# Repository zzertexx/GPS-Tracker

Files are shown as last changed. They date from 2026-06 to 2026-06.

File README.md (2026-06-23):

# GPS Tracker
### Use this bracelet to get live location and watch on any device 
> do not use to stalk people by giving them "unsuspicious" bracelet and looking where they are!!

## Zine


## Images

a


tracker-1
pcb-1

## How to use?
1. Order components from Bill of Materials and 3D Print case
2. Solder electronics and assembly into case
3. Insert SIM-Card with cellular data over 2G 
4. place your parameters in firmware "modem.h" line 5 and 8
5. Open Firmware via nRF connect in VS Code using Add existing application
6. Add build configuration: board: nRF52dk_nRF52832
7. Wait for build -> connect to board via SWD: github.com/AndruPol/nrf52832-recover

## Features
* Button to Sleep/Wake
* LED indicator of work status
* BLE advertising for future app
* Send location data to personal Google Sheet
* Charge with Type-C
* Compatible with lots of watch straps

> In current version, software may have significant bugs, improper code, not enough features, but I will edit/fix as I get hardware to debug

## 4-layer PCB
**Built in KiCad 10.99 night build**
> You can't export 3D model in default KiCad 10.0.3 because of error   
Ignore User.Comments

1 Layer - F.Cu  
2 Layer - 3.3V  
3 Layer - GND  
4 Layer - B.Cu  

## Why did I build it?
My bro asked me if I can build one. I don't have any interest for GPS locators, or needness for one. I just wanted to try myself in designing Wearable and also help my bro, so I did it and I felt real hardship of building in limited space. Currently my design is really bad and MUST be fixed in next updates by tightening free space. 

## Bill of Materials
| Name | Quantity |
| --- | --- |
| nRF52832 | x1 |
| CH340C | x1 |
| USB-C 14 pin | x1 |
| TP4056-42-ESOP8 | x1 |
| FS8205A | x1 |
| DW01A | x1 |
| XC6206P332MR-G | x1 |
| TXS0102DCUR | x1 |
| XUNPU SMN-303 | x1
| A7680C-LANV | x1 |
| ZIISOR TX4G-FPC-4015 | x1 |
| 16-213SURC/S530-A4/TR8 | x1 |
| 2450AT18A100E | x1 |
| NX2016SA-32MHZ | x1 |
| SC-20S,32.768kHz | x1 |
| BLM21PG300SN1D | x1 |
| ESDBW5V0A1 | x1 |
| LXES15AAA1-153 | x1 |
| L80-R | x1 |
| 500 mAh 503040 Battery | x1 |
| Straps - Galaxy watch 6 18mm | x1 |
| ST-LINK V2 | x1 |
| B3U-3000P LED Diode | x1 |
| LXES15AAA1-153 | x1 |
| 100nF C | x14 |
| 10uF C | x2 |
| 1uF C | x4 |
| 12pF C | x6 |
| 100uF C | x2 |
| 4.7uF C | x1 |
| 0.8pF C | x1 |
| 10pF C | x1 |
| 33pF C | x1 |
| 100pF C | x1 |
| 10pF C | x1 |
| 1.2K R | x1 |
| 1K R | x3 |
| 100 R | x5 |
| 5.1K R | x2 |
| 10K R | x1 |
| 0 R | x1 |
| 10uH L | x1 |
| 3.9nH L | x1 |
| 15nH L | x1 |
| M2 Screws | x8 |

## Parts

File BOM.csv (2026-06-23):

Component | ID | Price
nRF52832 | C77540 | $3,63 | https://www.lcsc.com/product-detail/C77540.html
CH340C | C84681 | $0,63 | https://www.lcsc.com/product-detail/C84681.html
USB-C 14 pin | C165948 | $0,18 | https://www.lcsc.com/product-detail/C165948.html
TP4056-42-ESOP8 | C16581 | $0,19 | https://www.lcsc.com/product-detail/C16581.html
FS8205A | C908265 | $0,07 | https://www.lcsc.com/product-detail/C908265.html
DW01A | C351410 | $0,04 | https://www.lcsc.com/product-detail/C351410.html
XC6206P332MR-G | C5446 | $0,11 | https://www.lcsc.com/product-detail/C5446.html
TXS0102DCUR | C53434 | $0,20 | https://www.lcsc.com/product-detail/C53434.html
XUNPU SMN-303 - SIM Card | C266888 | $0,48 | https://www.lcsc.com/product-detail/C266888.html
A7680C-LANV | C5381968 | $3,89 | https://www.lcsc.com/product-detail/C5381968.html
ZIISOR TX4G-FPC-4015 - Antenna for 2G | C454896 | $0,38 | https://www.lcsc.com/product-detail/C454896.html
16-213SURC/S530-A4/TR8 - Red LED | C74339 | $0,03 | https://www.lcsc.com/product-detail/C74339.html
2450AT18A100E - nRF antenna | C89334 | $0,52 | https://www.lcsc.com/product-detail/C89334.html
NX2016SA-32MHZ - 32MHz crystal | C5441424 | $0,44 | https://www.lcsc.com/product-detail/C5441424.html
SC-20S,32.768kHz - crystal | C97603 | $0,24 | https://www.lcsc.com/product-detail/C97603.html
BLM21PG300SN1D - Ferrite Bead | C16903 | $0,03 | https://www.lcsc.com/product-detail/C16903.html
ESDBW5V0A1 - A7680C TVS | C5173252 | $0,06 | https://www.lcsc.com/product-detail/C5173252.html
LXES15AAA1-153 - Antenna TVS | C5210978 | $0,04 | https://www.lcsc.com/product-detail/C5210978.html
L80-R | Aliexpress | $5,00 | https://aliexpress.ru/item/1005009368056644.html?sku_id=12000048887115112
Battery | Aliexpress | $3,66 | https://aliexpress.ru/item/1005008217717191.html?shpMethod=Other&sku_id=12000044268208548
Straps - Galaxy watch 6 18mm | Aliexpress | $1,18 | https://aliexpress.ru/item/1005007219292840.html?sku_id=12000039849739042
ST-LINK V2 | Aliexpress | $1,30 | https://aliexpress.ru/item/1005006144093275.html?sku_id=12000035958608625
B3U-3000P LED Diode | C963349 | $1,43 | https://www.lcsc.com/product-detail/C963349.html
Capacitors
CL05B104KO5NNNC - C 100nF | C1525 | $0,01 | https://www.lcsc.com/product-detail/C1525.html
CL10A106KP8NNNC - C 10uF | C19702 | $0,02 | https://www.lcsc.com/product-detail/C19702.html
CL10A105KB8NNNC - C 1uF | C15849 | $0,01 | https://www.lcsc.com/product-detail/C15849.html
0402CG120J500NT - C 12pF | C1547 | $0,01 | https://www.lcsc.com/product-detail/C1547.html
CK1A101M-CRD54 - C 100uF | C3001231 | $0,03 | https://www.lcsc.com/product-detail/C3001231.html
CL10A475KO8NNNC - C 4.7uF | C19666 | $0,01 | https://www.lcsc.com/product-detail/C19666.html
CL10C0R8BB8NNNC - C 0.8pF | C21357 | $0,01 | https://www.lcsc.com/product-detail/C21357.html
CL05C100JB5NNNC - C 10pF | C32949 | $0,01 | https://www.lcsc.com/product-detail/C32949.html
0402CG330J500NT - C 33pF | C1562 | $0,01 | https://www.lcsc.com/product-detail/C1562.html
0402CG101J500NT - C 100pF | C1546 | $0,01 | https://www.lcsc.com/product-detail/C1546.html
Resistors
0603WAF1201T5E - R 1.2K | C22765 | $0,01 | https://www.lcsc.com/product-detail/C22765.html
0402WGF1001TCE - R 1K | C11702 | $0,01 | https://www.lcsc.com/product-detail/C11702.html
0402WGF1000TCE - R 100 | C25076 | $0,01 | https://www.lcsc.com/product-detail/C25076.html
0402WGF5101TCE - R 5.1K | C25905 | $0,01 | https://www.lcsc.com/product-detail/C25905.html
0805W8F1002T5E - R 10K | C17414 | $0,01 | https://www.lcsc.com/product-detail/C17414.html
0402WGF0000TCE R - 0 | C17168 | $0,01 | https://www.lcsc.com/product-detail/C17168.html
Inductors
SDFL2012S100KTF - L 10uH | C1046 | $0,05 | https://www.lcsc.com/product-detail/C1046.html
SDCL1005C3N9STDF - L 3.9nH | C14033 | $0,01 | https://www.lcsc.com/product-detail/C14033.html
SDCL1005C15NJTDF - L 15nH | C27143 | $0,01 | https://www.lcsc.com/product-detail/C27143.html

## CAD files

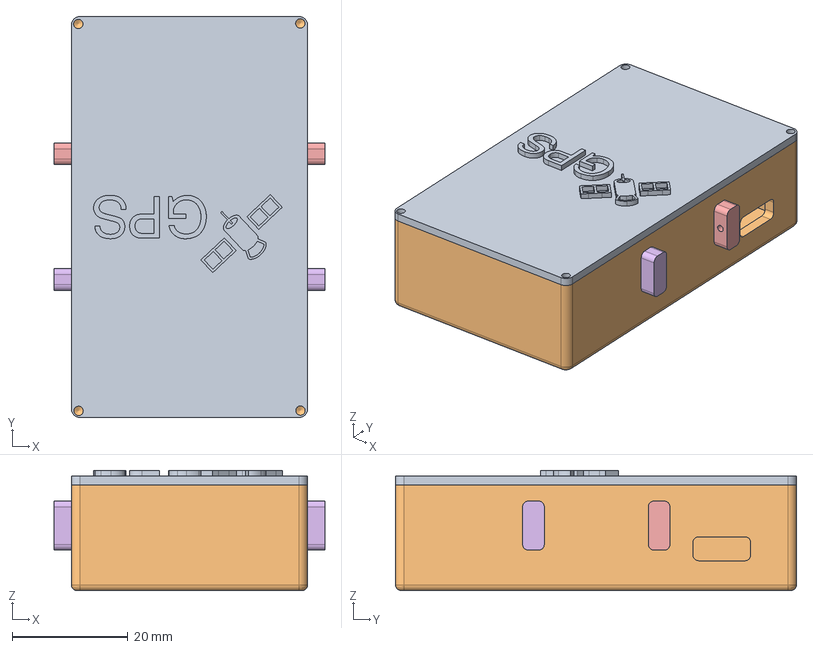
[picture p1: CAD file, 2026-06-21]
CAD/GPS_Case.step
46.9 x 69.4 x 20.8 mm

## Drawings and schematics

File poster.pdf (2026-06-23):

# GPS Tracker

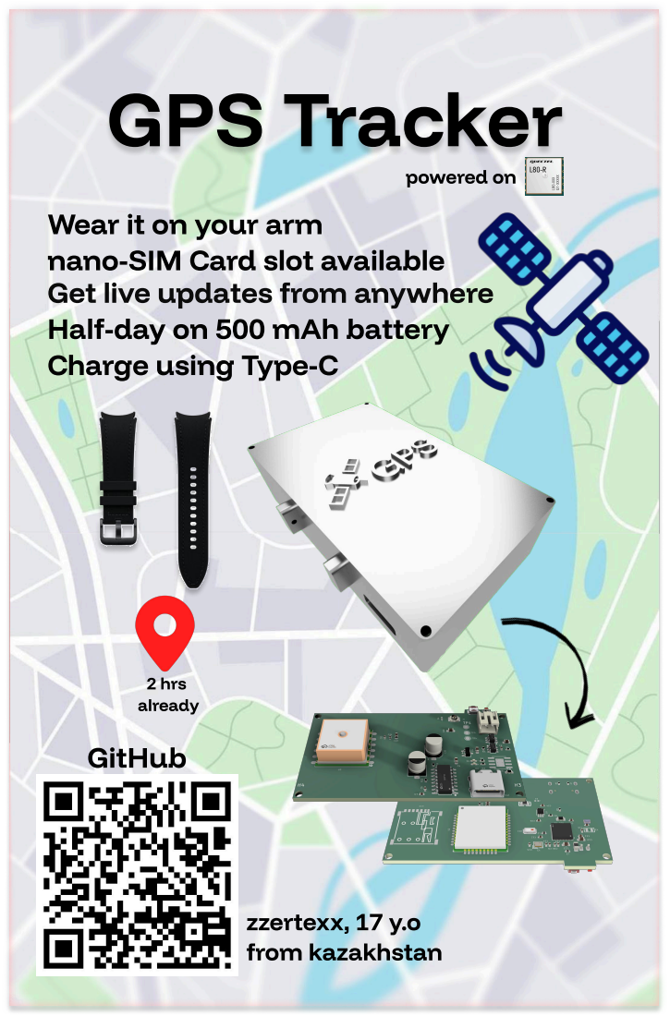
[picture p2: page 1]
powered on; 2 hrs; already; GitHub; zzertexx, 17 y.o; from kazakhstan

Wear it on your arm
nano-SIM Card slot available
Get live updates from anywhere
Half-day on 500 mAh battery
Charge using Type-C

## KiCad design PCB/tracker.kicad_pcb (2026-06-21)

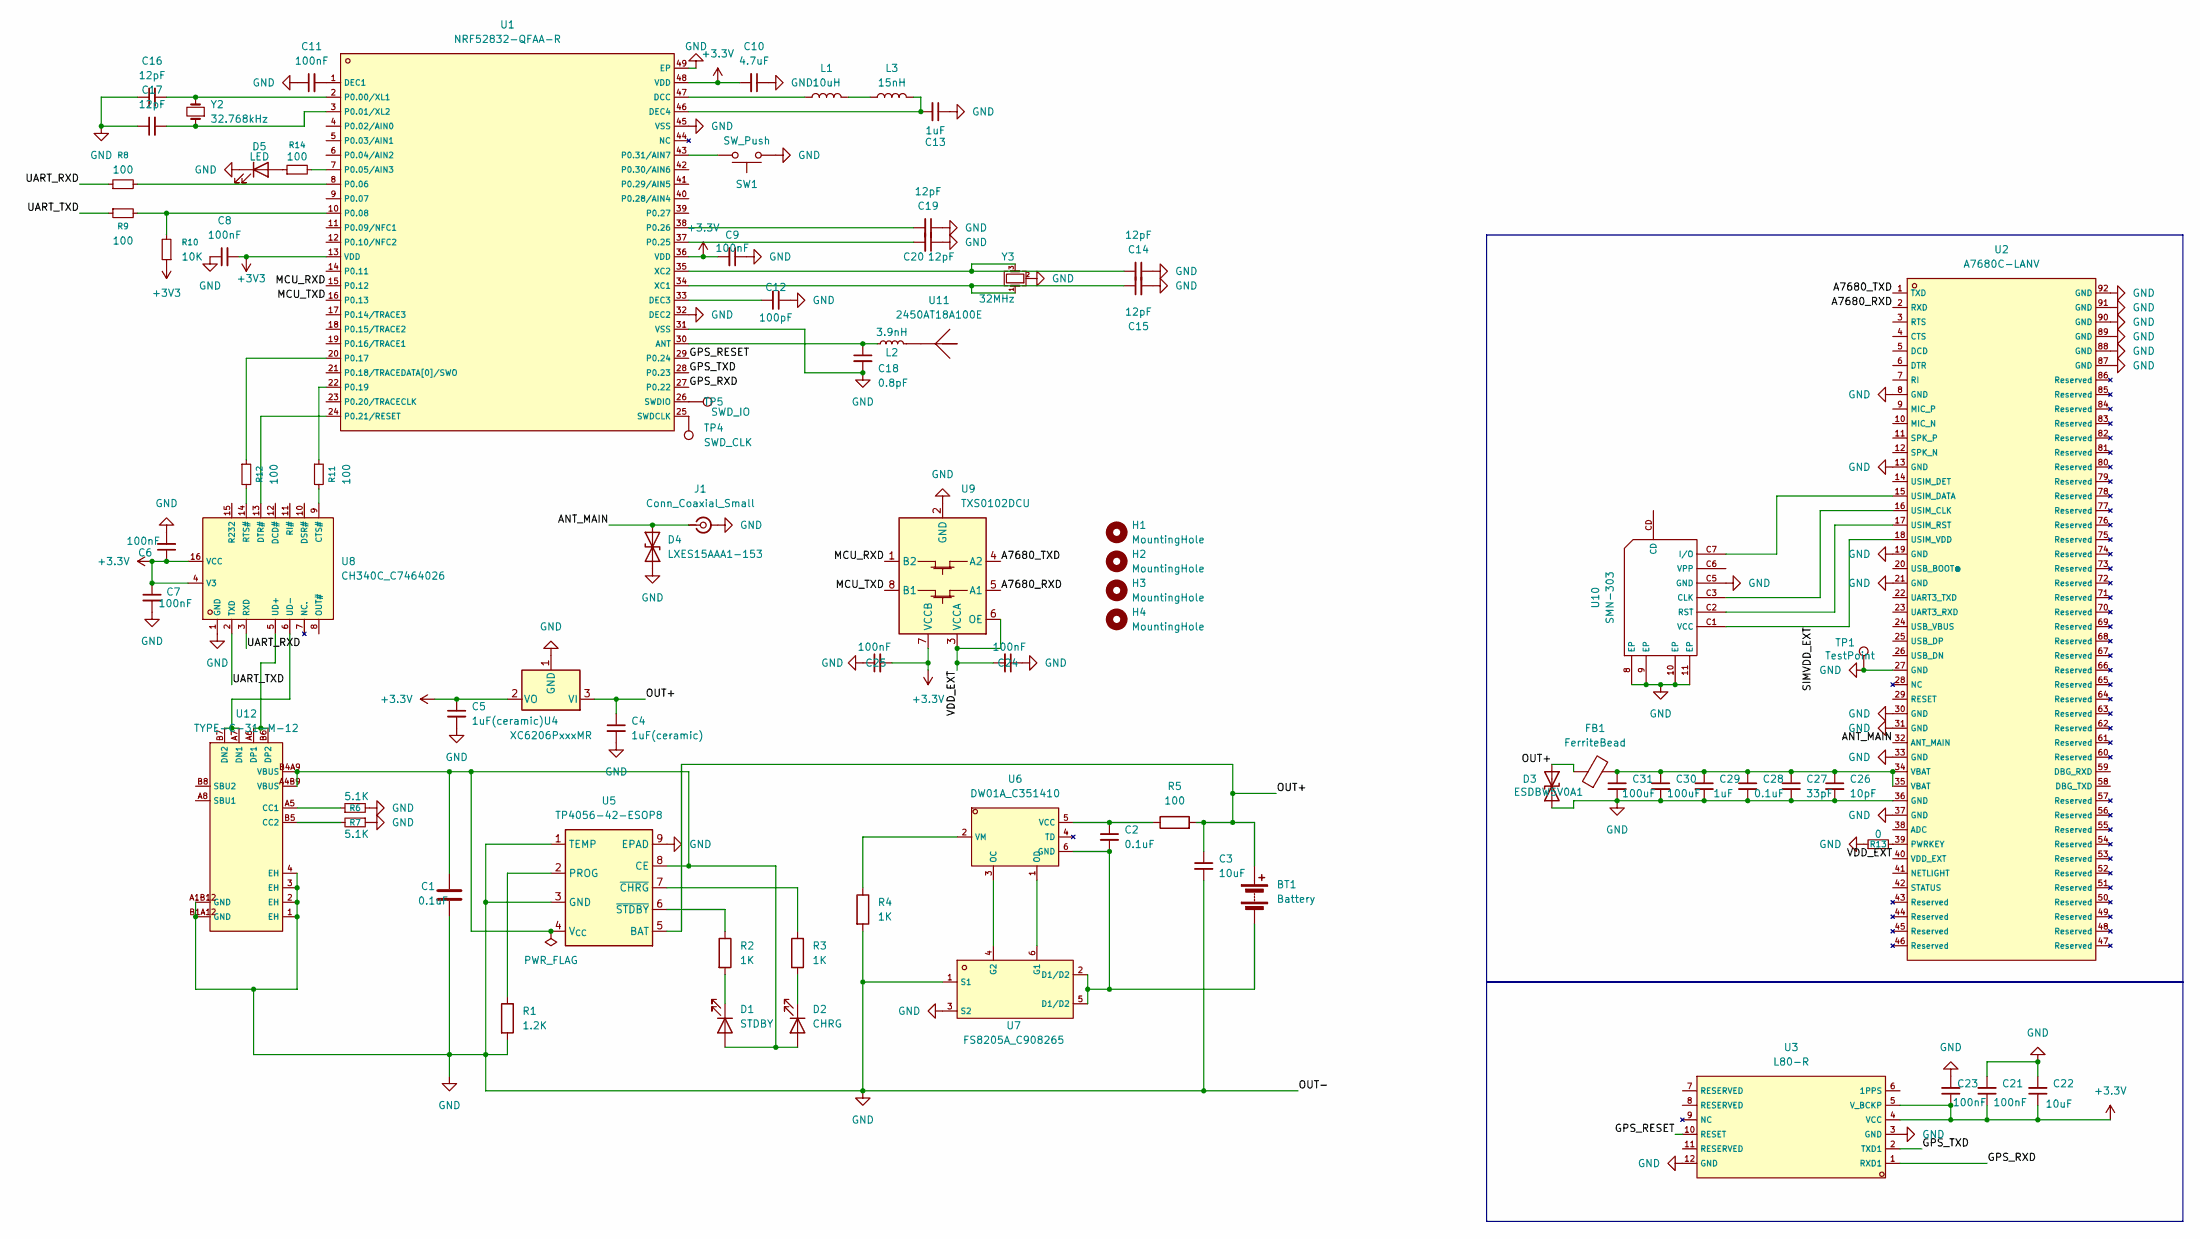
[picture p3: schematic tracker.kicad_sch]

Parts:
BT1: Battery; JST_PH_S2B-PH-K_1x02_P2.00mm_Horizontal
C1, C2, C28: 0.1uF; C_0402_1005Metric
C3, C22: 10uF; C_0603_1608Metric
C4, C5: 1uF(ceramic); C_0603_1608Metric
C6, C7, C8, C9, C11, C21, C23, C24, C25: 100nF; C_0402_1005Metric
C10: 4.7uF; C_0603_1608Metric
C12: 100pF; C_0402_1005Metric
C13, C29: 1uF; C_0603_1608Metric
C14, C15, C16, C17, C19, C20: 12pF; C_0402_1005Metric
C18: 0.8pF; C_0603_1608Metric_Pad1.08x0.95mm_HandSolder
C26: 10pF; C_0402_1005Metric
C27: 33pF; C_0402_1005Metric
C30, C31: 100uF; CP_Elec_5x5.4
D1: STDBY; LED_0402_1005Metric_Pad0.77x0.64mm_HandSolder
D2: CHRG; LED_0402_1005Metric_Pad0.77x0.64mm_HandSolder
D3: ESDBW5V0A1; D_0402_1005Metric
D4: LXES15AAA1-153; D_0402_1005Metric
D5: LED; LED_Kingbright_APA1606_1.6x0.6mm_Horizontal
FB1: FerriteBead; L0805
H1, H2, H3, H4: MountingHole; MountingHole_2.2mm_M2
J1: Conn_Coaxial_Small; U.FL_Hirose_U.FL-R-SMT-1_Vertical
L1: 10uH; L_0805_2012Metric
L2: 3.9nH; L_0402_1005Metric
L3: 15nH; L_0402_1005Metric
R1: 1.2K; R_0603_1608Metric
R2, R3, R4: 1K; R_0402_1005Metric
R5, R8, R9, R11, R12: 100; R_0402_1005Metric
R6, R7: 5.1K; R_0402_1005Metric
R10: 10K; R_0805_2012Metric
R13: 0; R_0402_1005Metric
R14: 100; C_0402_1005Metric
SW1: SW_Push; KEY-SMD_B3U-3000P
TP1: TestPoint; TestPoint_Pad_D1.5mm
TP4: SWD_CLK; TestPoint_Pad_D1.5mm
TP5: SWD_IO; TestPoint_Pad_D1.5mm
U1: NRF52832-QFAA-R; QFN-48_L6.0-W6.0-P0.40-BL-EP3.8; LCSC C77540
U2: A7680C-LANV; LCC-LAG_L17.6-W15.7_A7680C; LCSC C5381968
U3: L80-R; GPSM-SMD_L80-R; LCSC C188357
U4: XC6206PxxxMR; SOT-23-3
U5: TP4056-42-ESOP8; SOIC-8-1EP_3.9x4.9mm_P1.27mm_EP2.41x3.3mm_ThermalVias
U6: DW01A_C351410; SOT-23-6_L2.9-W1.6-P0.95-LS2.8-BL; LCSC C351410
U7: FS8205A_C908265; SOT-23-6_L2.9-W1.6-P0.95-LS2.8-BR; LCSC C908265
U8: CH340C_C7464026; SOP-16_L10.0-W3.9-P1.27-LS6.0-BL; LCSC C7464026
U9: TXS0102DCU; VSSOP-8_2.3x2mm_P0.5mm
U10: SMN-303; SIM-SMD_SMN-303; LCSC C266888
U11: 2450AT18A100E; ANT-SMD_L3.2-W1.6; LCSC C89334
U12: TYPE-C-31-M-12; USB-C_SMD-TYPE-C-31-M-12_1; LCSC C165948
Y2: 32.768kHz; OSC-SMD_L2.0-W1.2
Y3: 32MHz; CRYSTAL-SMD_4P-L2.0-W1.6-BL

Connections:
+3.3V: C5.1, C6.1, C7.1, C9.2, C10.2, C21.1, C22.1, C23.1, C25.2, U1.36 (VDD), U1.48 (VDD), U3.4 (VCC), U3.5 (V_BCKP), U4.2 (VO), U8.4 (V3), U8.16 (VCC), U9.7 (VCCB)
+3V3: C8.2, R10.1, U1.13 (VDD)
/A7680_RXD: U2.2 (RXD), U9.5 (A1)
/A7680_TXD: U2.1 (TXD), U9.4 (A2)
/ANT_MAIN: D4.2 (A2), J1.1 (In), U2.32 (ANT_MAIN)
/GPS_RESET: U1.29 (P0.24), U3.10 (RESET)
/GPS_RXD: U1.27 (P0.22), U3.1 (RXD1)
/GPS_TXD: U1.28 (P0.23), U3.2 (TXD1)
/MCU_RXD: U1.15 (P0.12), U9.1 (B2)
/MCU_TXD: U1.16 (P0.13), U9.8 (B1)
/OUT+: BT1.1 (+), C3.1, C4.1, D3.2 (A2), FB1.1, R5.2, U4.3 (VI), U5.5 (BAT)
/SIMVDD_EXT: U2.18 (USIM_VDD), U10.C1 (VCC)
/UART_RXD: R8.1, U8.3 (RXD)
/UART_TXD: R9.1, U8.2 (TXD)
/VDD_EXT: C24.2, U2.40 (VDD_EXT), U9.3 (VCCA), U9.6 (OE)
GND: C1.2, C3.2, C4.2, C5.2, C6.2, C7.2, C8.1, C9.1, C10.1, C11.1, C12.1, C13.1, C14.1, C15.2, C16.1, C17.1, C18.2, C19.1, C20.1, C21.2, C22.2, C23.2, C24.1, C25.1, C26.2, C27.2, C28.2, C29.2, C30.2, C31.2, D3.1 (A1), D4.1 (A1), D5.1 (K), J1.2 (Ext), R1.2, R4.2, R6.2, R7.1, R13.1, SW1.1, TP1.1 (1_1), U1.31 (VSS), U1.32 (DEC2), U1.45 (VSS), U1.49 (EP), U2.8 (GND), U2.13 (GND), U2.19 (GND), U2.21 (GND), U2.27 (GND), U2.30 (GND), U2.31 (GND), U2.33 (GND), U2.36 (GND), U2.37 (GND), U2.87 (GND), U2.88 (GND), U2.89 (GND), U2.90 (GND), U2.91 (GND), U2.92 (GND), U3.3 (GND), U3.12 (GND), U4.1 (GND), U5.1 (TEMP), U5.3 (GND), U5.9 (EPAD), U7.1 (S1), U7.3 (S2), U8.1 (GND), U9.2 (GND), U10.8 (EP), U10.9 (EP), U10.10 (EP), U10.11 (EP), U10.C5 (GND), U12.1 (EH), U12.2 (EH), U12.3 (EH), U12.4 (EH), U12.A1B12 (GND), U12.B1A12 (GND), Y3.2 (G), Y3.4 (G)
unnamed: BT1.2 (-), C2.2, U6.6 (GND), U7.2 (D1/D2), U7.5 (D1/D2)
unnamed: C26.1, C27.1, C28.1, C29.1, C30.1, C31.1, FB1.2, U2.34 (VBAT), U2.35 (VBAT)
unnamed: C1.1, D1.2 (A), D2.2 (A), U5.4 (V_{CC}), U5.8 (CE), U12.A4B9 (VBUS), U12.B4A9 (VBUS)
unnamed: D1.1 (K), R2.2
unnamed: D2.1 (K), R3.2
unnamed: D5.2 (A), R14.1
unnamed: L1.2, L3.1
unnamed: C18.1, L2.1, U1.30 (ANT)
unnamed: L1.1, U1.47 (DCC)
unnamed: C11.2, U1.1 (DEC1)
unnamed: C12.2, U1.33 (DEC3)
unnamed: C13.2, L3.2, U1.46 (DEC4)
unnamed: C16.2, U1.2 (P0.00/XL1), Y2.2
unnamed: C17.2, U1.3 (P0.01/XL2), Y2.1
unnamed: R14.2, U1.7 (P0.05/AIN3)
unnamed: R8.2, U1.8 (P0.06)
unnamed: R9.2, R10.2, U1.10 (P0.08)
unnamed: R12.1, U1.20 (P0.17)
unnamed: R11.1, U1.22 (P0.19)
unnamed: U1.24 (P0.21/RESET), U8.13 (DTR#)
unnamed: C20.2, U1.37 (P0.25)
unnamed: C19.2, U1.38 (P0.26)
unnamed: SW1.2, U1.43 (P0.31/AIN7)
unnamed: TP4.1 (1_1), U1.25 (SWDCLK)
unnamed: TP5.1 (1_1), U1.26 (SWDIO)
unnamed: C15.1, U1.34 (XC1), Y3.1
unnamed: C14.2, U1.35 (XC2), Y3.3
unnamed: R13.2, U2.39 (PWRKEY)
unnamed: R1.1, U5.2 (PROG)
unnamed: R3.1, U5.7 (~CHRG)
unnamed: R2.1, U5.6 (~STDBY)
unnamed: U6.3 (OC), U7.4 (G2)
unnamed: U6.1 (OD), U7.6 (G1)
unnamed: C2.1, R5.1, U6.5 (VCC)
unnamed: R4.1, U6.2 (VM)
unnamed: R11.2, U8.9 (CTS#)
unnamed: R12.2, U8.14 (RTS#)
unnamed: U2.16 (USIM_CLK), U10.C3 (CLK)
unnamed: U2.15 (USIM_DATA), U10.C7 (I/O)
unnamed: U2.17 (USIM_RST), U10.C2 (RST)
unnamed: L2.2, U11.1 (ANT_1)
unnamed: R6.1, U12.A5 (CC1)
unnamed: R7.2, U12.B5 (CC2)
unnamed: U8.6 (UD-), U12.A7 (DN1), U12.B7 (DN2)
unnamed: U8.5 (UD+), U12.A6 (DP1), U12.B6 (DP2)

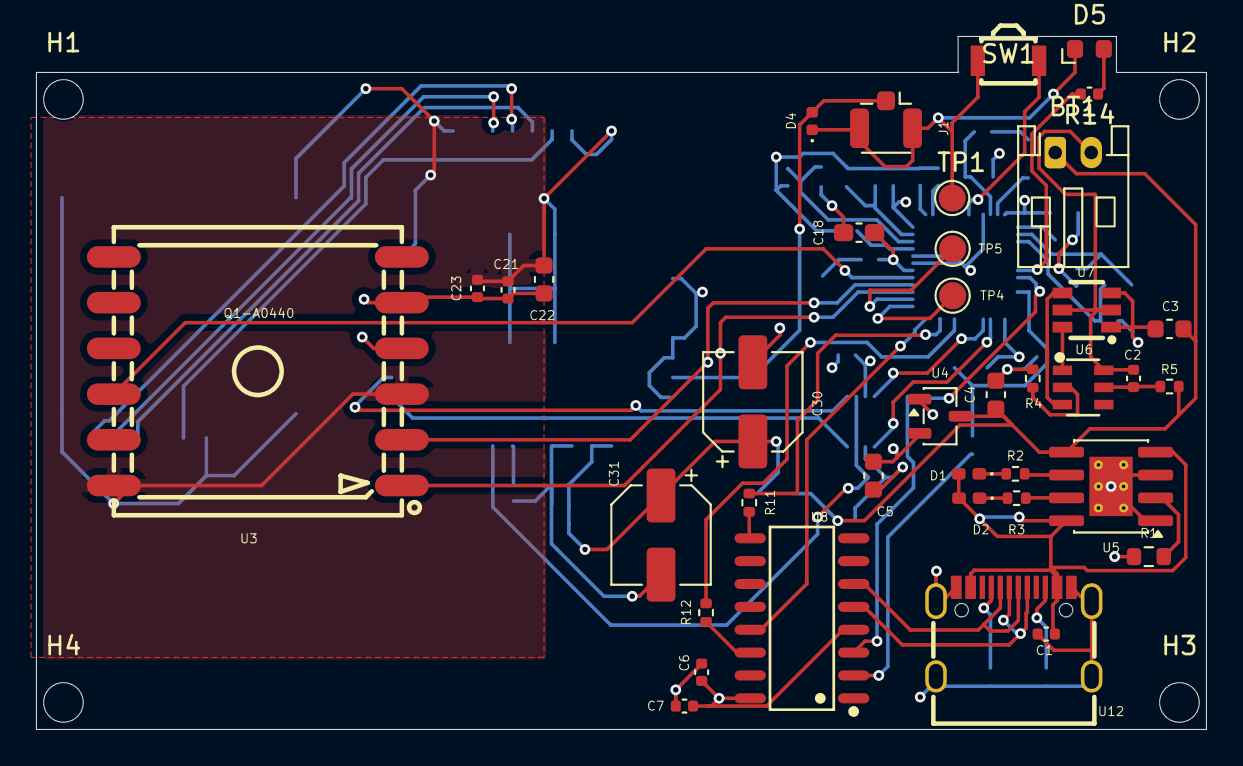
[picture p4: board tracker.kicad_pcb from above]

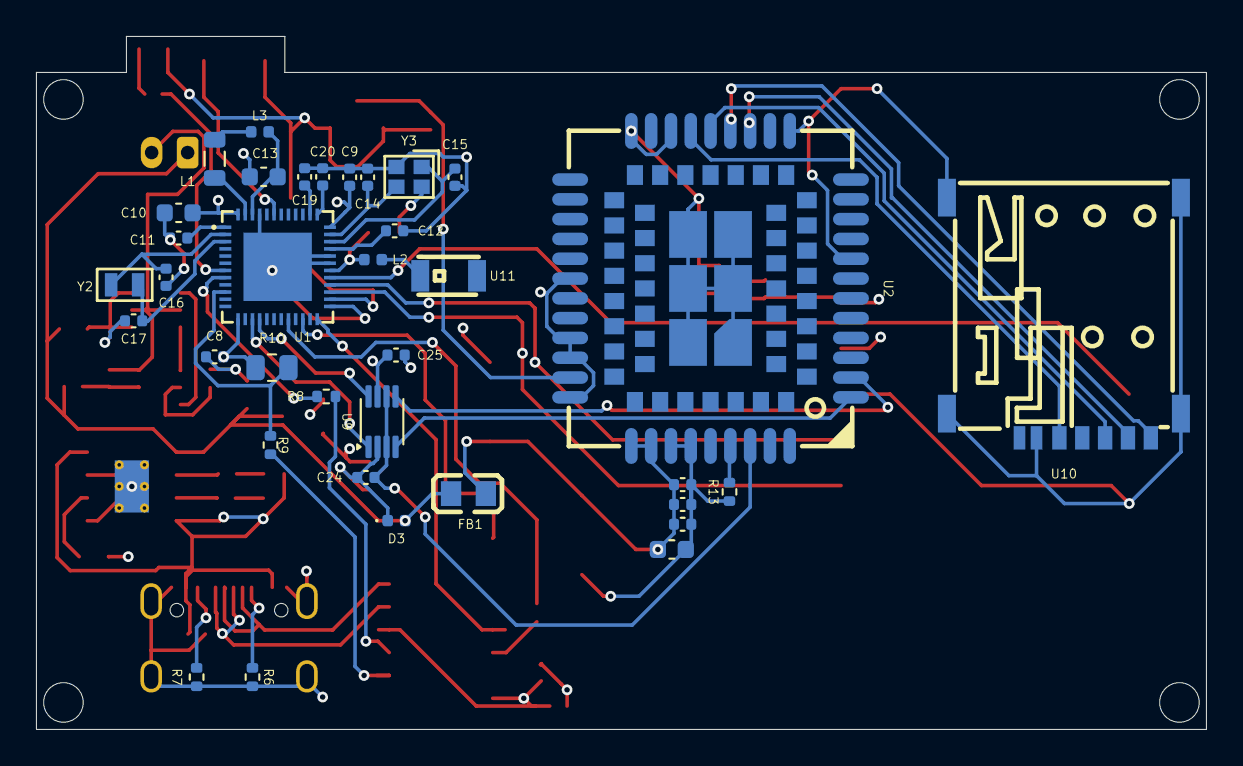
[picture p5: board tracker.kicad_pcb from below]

Board: 4 copper layers, 65.0 x 38.5 mm, 78 parts (36 on the bottom side), 61 nets.

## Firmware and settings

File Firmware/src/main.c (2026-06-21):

#include <zephyr/kernel.h>
#include <zephyr/sys/printk.h>
#include "uart_switch.h"
#include "led.h"
#include "gps.h"
#include "modem.h"
#include "ble.h"
#include "state_machine.h"

int main(void)
{
    printk("AKT-01 tracker boot\n");

    uart_switch_init();
    led_init();
    gps_init();
    ble_init();
    modem_init();
    state_machine_init();

    printk("Boot complete\n");

    state_machine_run();

    return 0;
}

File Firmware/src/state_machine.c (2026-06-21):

#include "state_machine.h"
#include "gps.h"
#include "modem.h"
#include "ble.h"
#include "led.h"
#include <zephyr/kernel.h>
#include <zephyr/drivers/gpio.h>
#include <zephyr/sys/printk.h>

/* ── State ───────────────────────────────────────────────────────────── */
typedef enum { STATE_SLEEP, STATE_AWAKE } device_state_t;
static volatile device_state_t m_state = STATE_SLEEP;

/* ── Button ──────────────────────────────────────────────────────────── */
#define BUTTON_NODE DT_ALIAS(sw0)
static const struct gpio_dt_spec m_btn = GPIO_DT_SPEC_GET(BUTTON_NODE, gpios);
static struct gpio_callback      m_btn_cb;

static K_SEM_DEFINE(m_btn_sem, 0, 1);

static void button_isr(const struct device *dev, struct gpio_callback *cb,
                        uint32_t pins)
{
    ARG_UNUSED(dev);
    ARG_UNUSED(cb);
    ARG_UNUSED(pins);
    k_sem_give(&m_btn_sem);
}

/* ── Cycle timer + semaphore ─────────────────────────────────────────── */
static K_SEM_DEFINE(m_cycle_sem, 0, 1);

static void cycle_timer_cb(struct k_timer *t)
{
    ARG_UNUSED(t);
    k_sem_give(&m_cycle_sem);
}

K_TIMER_DEFINE(m_cycle_timer, cycle_timer_cb, NULL);

/* ── Cycle thread ────────────────────────────────────────────────────── */
#define CYCLE_THREAD_STACK  4096
#define CYCLE_THREAD_PRIO   5

static void cycle_thread_fn(void *a, void *b, void *c)
{
    ARG_UNUSED(a); ARG_UNUSED(b); ARG_UNUSED(c);

    while (1) {
        k_sem_take(&m_cycle_sem, K_FOREVER);

        if (m_state != STATE_AWAKE) {
            continue;
        }

        printk("Cycle: starting fix→upload\n");

        /* ── GPS ─────────────────────────────────────────────────────── */
        gps_fix_t fix;
        bool got_fix = gps_acquire_fix(&fix, GPS_FIX_TIMEOUT_MS);

        if (!got_fix) {
            printk("Cycle: no GPS fix — skipping upload\n");
            led_blink_fail();
            continue;
        }

        /* ── Upload ──────────────────────────────────────────────────── */
        bool uploaded = modem_send_location(fix.latitude, fix.longitude);

        if (!uploaded) {
            printk("Cycle: upload failed\n");
            led_blink_fail();
        } else {
            printk("Cycle: upload OK\n");

            char buf[64];
            int lat_deg  = (int)(fix.latitude < 0 ? -fix.latitude : fix.latitude);
            int lat_frac = (int)((fix.latitude < 0 ? -fix.latitude : fix.latitude) * 1e6) % 1000000;
            int lon_deg  = (int)(fix.longitude < 0 ? -fix.longitude : fix.longitude);
            int lon_frac = (int)((fix.longitude < 0 ? -fix.longitude : fix.longitude) * 1e6) % 1000000;

            snprintf(buf, sizeof(buf), "%s%d.%06d,%s%d.%06d",
                     fix.latitude  < 0 ? "-" : "", lat_deg, lat_frac,
                     fix.longitude < 0 ? "-" : "", lon_deg, lon_frac);
            ble_send_status(buf);
        }
    }
}

K_THREAD_DEFINE(cycle_tid,
                CYCLE_THREAD_STACK,
                cycle_thread_fn,
                NULL, NULL, NULL,
                CYCLE_THREAD_PRIO, 0, 0);

/* ── State transitions ───────────────────────────────────────────────── */
static void enter_awake(void)
{
    printk("-> AWAKE\n");
    m_state = STATE_AWAKE;
    ble_start();
    k_sem_give(&m_cycle_sem);
    k_timer_start(&m_cycle_timer,
                  K_SECONDS(CYCLE_INTERVAL_S),
                  K_SECONDS(CYCLE_INTERVAL_S));
}

static void enter_sleep(void)
{
    printk("-> SLEEP\n");
    m_state = STATE_SLEEP;
    k_timer_stop(&m_cycle_timer);
    ble_stop();
    gps_enter_standby();
    modem_sleep();
}

/* ── Public API ──────────────────────────────────────────────────────── */

void state_machine_init(void)
{
    gpio_pin_configure_dt(&m_btn, GPIO_INPUT);
    gpio_pin_interrupt_configure_dt(&m_btn, GPIO_INT_EDGE_TO_ACTIVE);
    gpio_init_callback(&m_btn_cb, button_isr, BIT(m_btn.pin));
    gpio_add_callback(m_btn.port, &m_btn_cb);

    printk("State machine ready, starting in SLEEP\n");
}

void state_machine_run(void)
{
    while (1) {
        k_sem_take(&m_btn_sem, K_FOREVER);
        k_sleep(K_MSEC(50)); /* debounce */

        while (k_sem_take(&m_btn_sem, K_NO_WAIT) == 0) {
        }

        if (m_state == STATE_SLEEP) {
            enter_awake();
        } else {
            enter_sleep();
        }
    }
}
